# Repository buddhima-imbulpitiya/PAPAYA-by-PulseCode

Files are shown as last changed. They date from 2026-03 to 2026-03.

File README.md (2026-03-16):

## P.A.P.A.Y.A._by_PulseCode

> **Posture Analysis and Proactive Alignment for Your Awareness**  
> A smart cushion that detects poor sitting posture in real-time and provides subtle haptic feedback to encourage healthy sitting habits.

🏆 **2nd Runners Up – Brainstorm 2025**  
📍 **University of Moratuwa – BM1190 Engineering Design Project**

---

## 📜 Project Overview
PulseCode is a human-centered ergonomic solution to combat posture-related back pain among desk-bound individuals.  
It combines **pressure sensors**, **distance sensing**, and **vibration feedback** to help users build healthy sitting habits without intrusive devices.

---

## 🛠 Features
- **8x FSR402 pressure sensors** for seat pressure mapping
- **Ultrasonic sensor (HC-SR04)** for back distance measurement
- **ATmega328P microcontroller** for posture logic
- **Vibration motor** for subtle posture alerts
- **Custom PCB** and **SolidWorks-designed enclosures**
- **LED battery level indicator**, USB-C charging, 7.4V Li-ion battery
- **Automotive-grade foam cushion**

---
**Final Product :**
<p align="center">
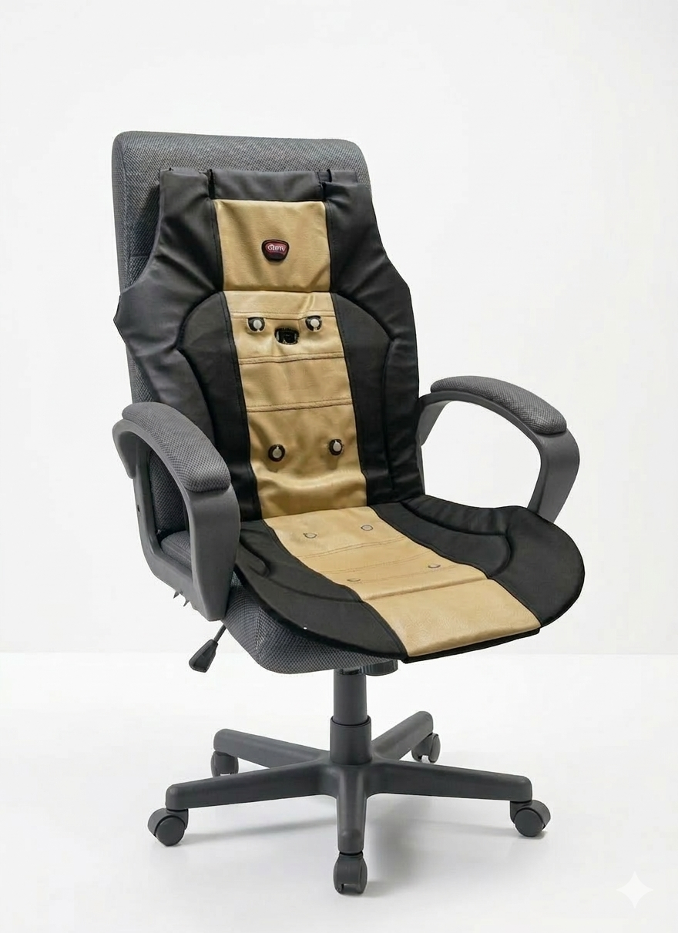
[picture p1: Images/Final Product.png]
  
  &nbsp;&nbsp;&nbsp;&nbsp; &nbsp;&nbsp; &nbsp;  &nbsp; &nbsp; &nbsp;&nbsp; &nbsp; &nbsp; &nbsp; &nbsp; &nbsp; &nbsp; 
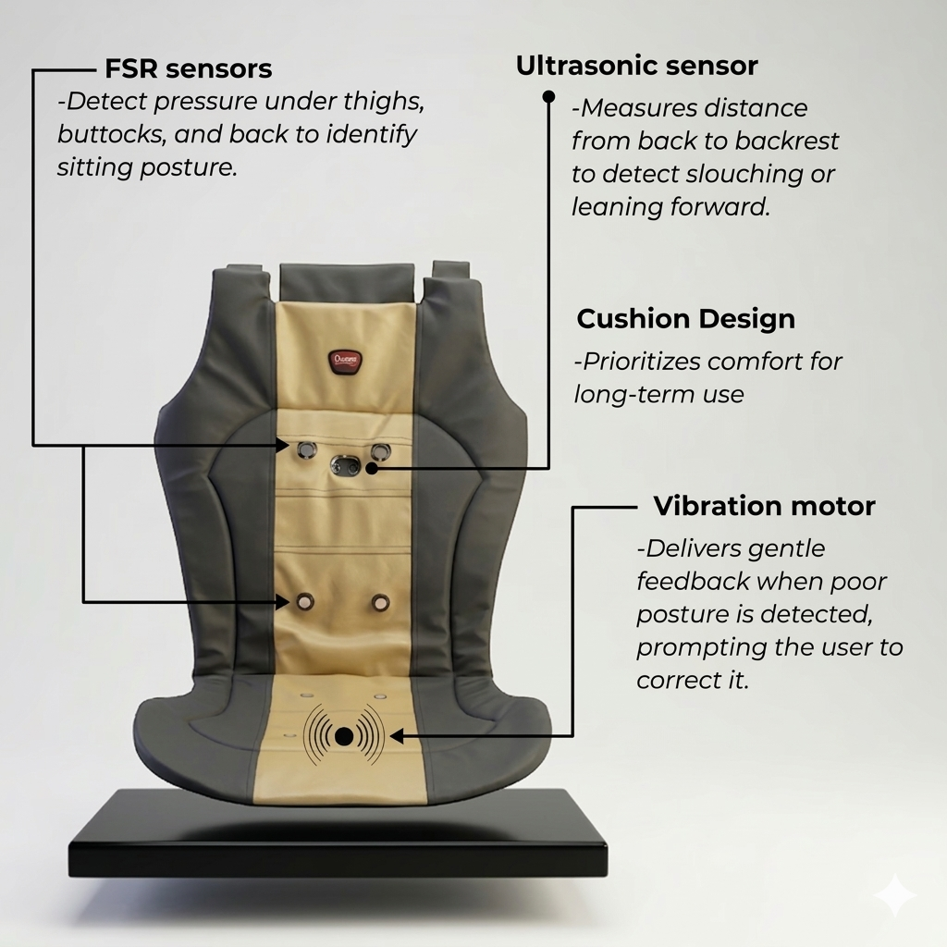
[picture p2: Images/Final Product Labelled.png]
  
  &nbsp;&nbsp;&nbsp;
</p>

---

**System Architecture & Schematic :**

<p align="center">
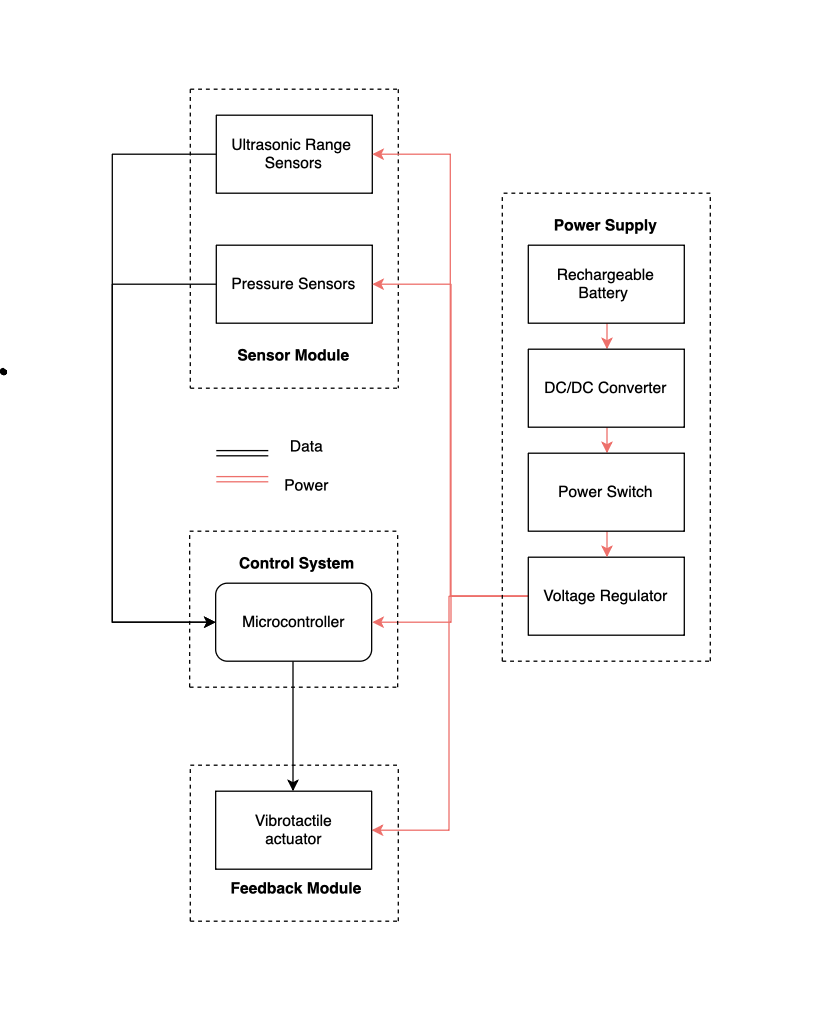
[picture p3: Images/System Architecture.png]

&nbsp;&nbsp;&nbsp;&nbsp; &nbsp;&nbsp; &nbsp;  &nbsp;&nbsp; &nbsp; &nbsp; &nbsp;&nbsp; &nbsp; &nbsp; &nbsp;&nbsp; &nbsp;&nbsp;  &nbsp; &nbsp; &nbsp; &nbsp;&nbsp;  &nbsp;&nbsp;&nbsp; &nbsp;
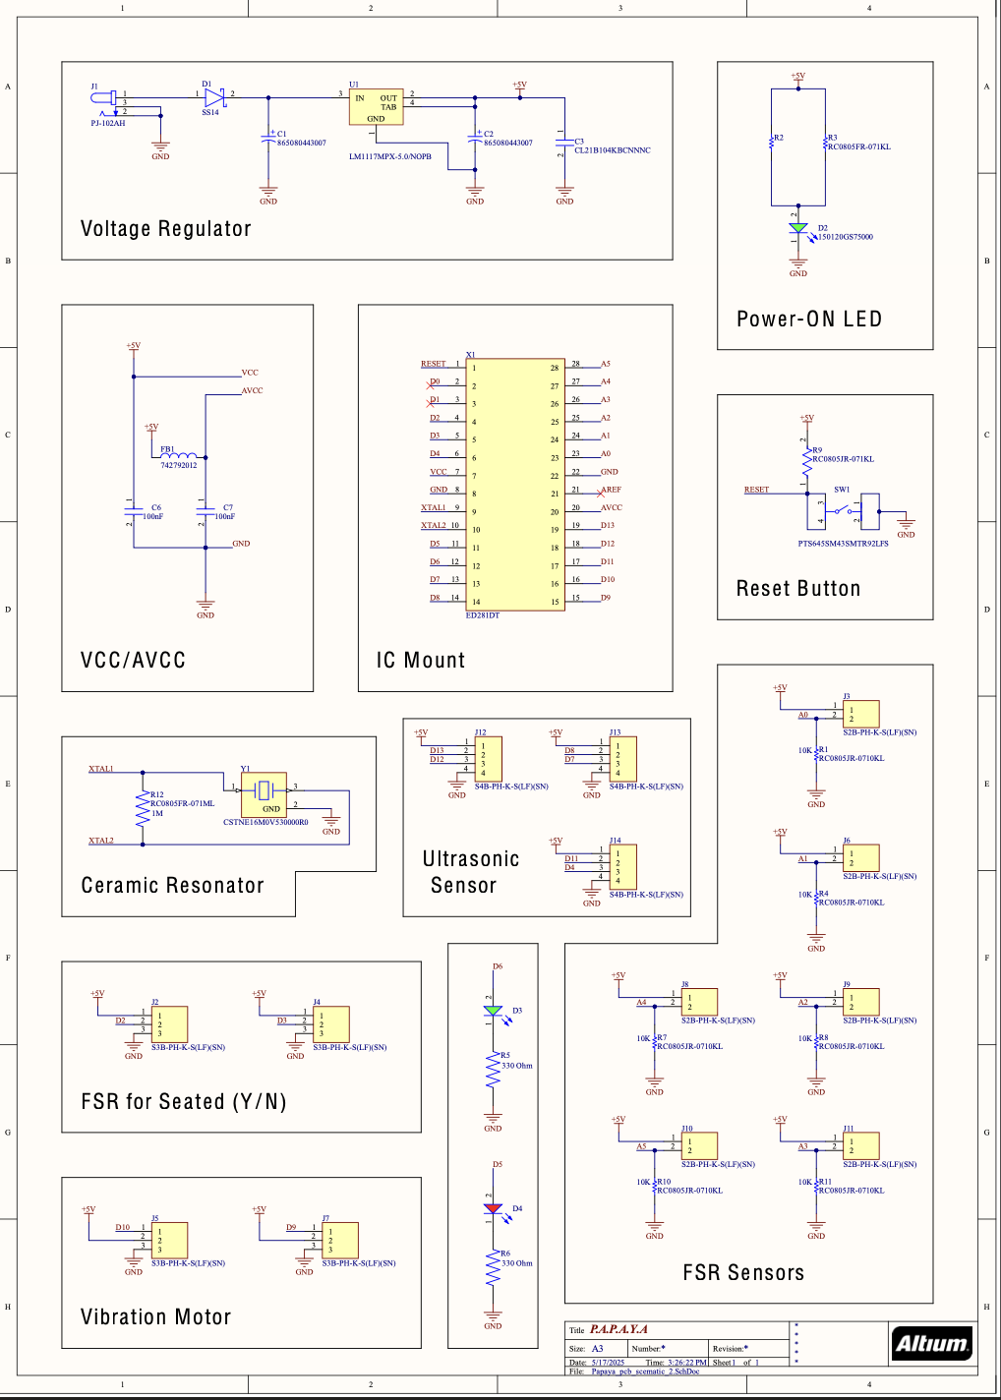
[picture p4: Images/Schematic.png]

</p>

---

**PCB Design :**

<p align="center">
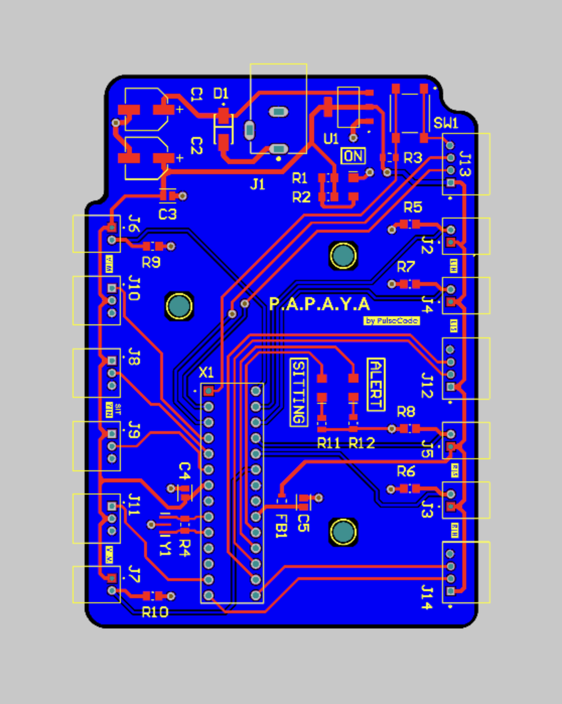
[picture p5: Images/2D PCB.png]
  
  &nbsp;&nbsp;&nbsp;
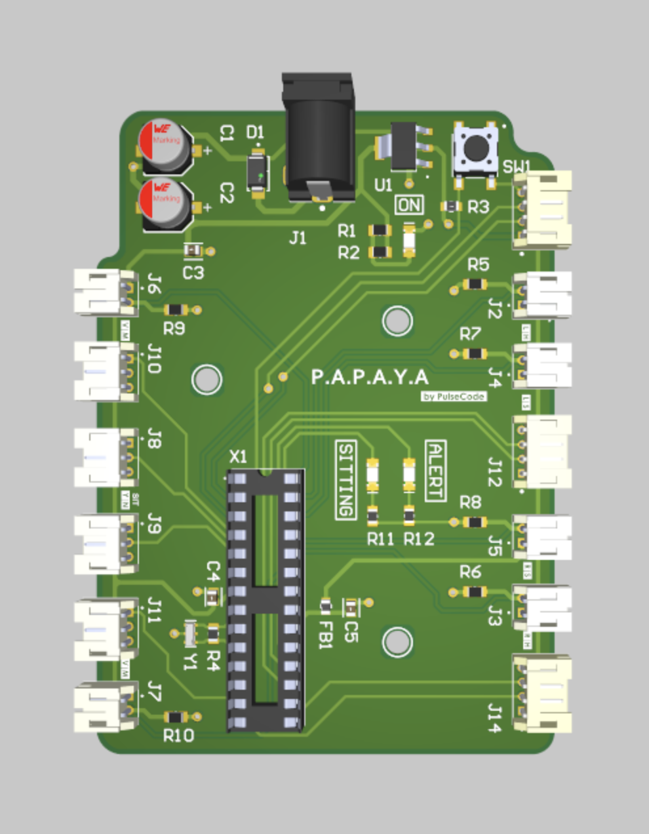
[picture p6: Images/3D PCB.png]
  
  &nbsp;&nbsp;&nbsp;
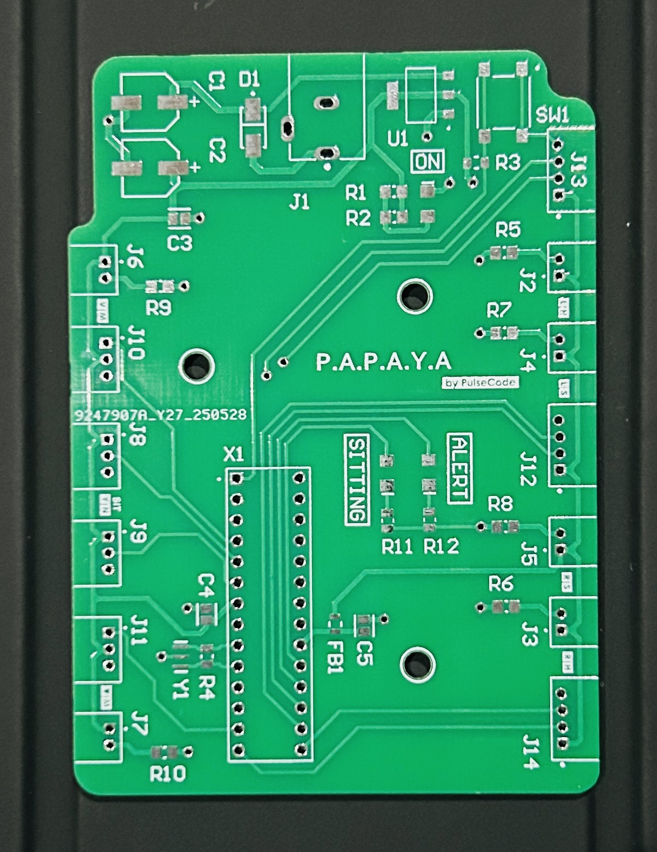
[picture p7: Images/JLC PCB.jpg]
  
</p>

---

**Enclosure Design :**

<p align="center">
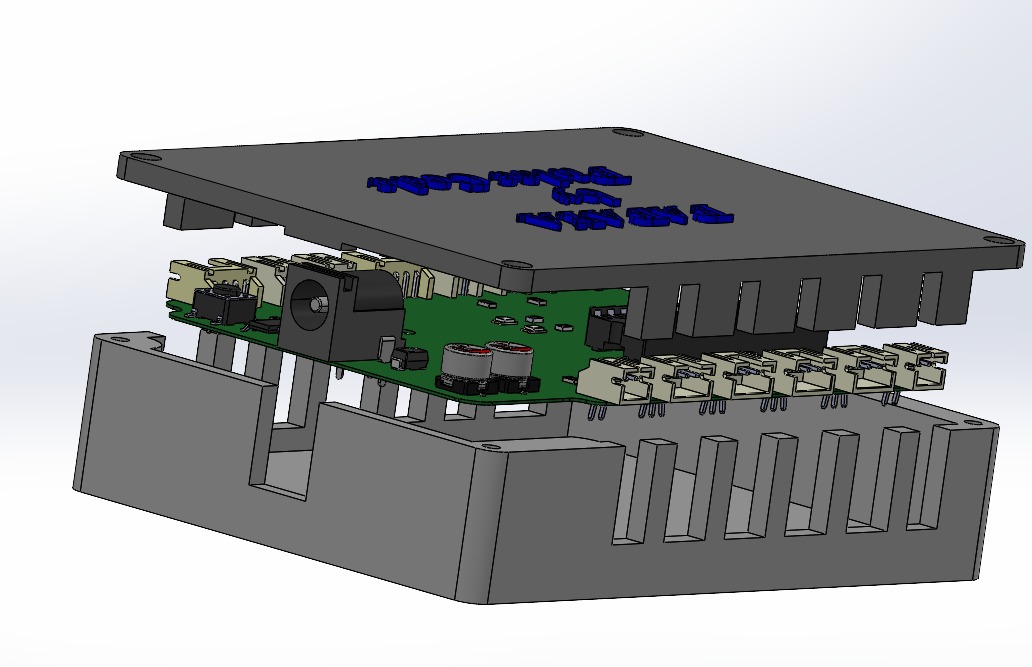
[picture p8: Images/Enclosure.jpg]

  &nbsp;&nbsp;&nbsp;&nbsp;&nbsp;&nbsp;&nbsp;&nbsp;&nbsp;&nbsp;&nbsp;&nbsp;&nbsp;
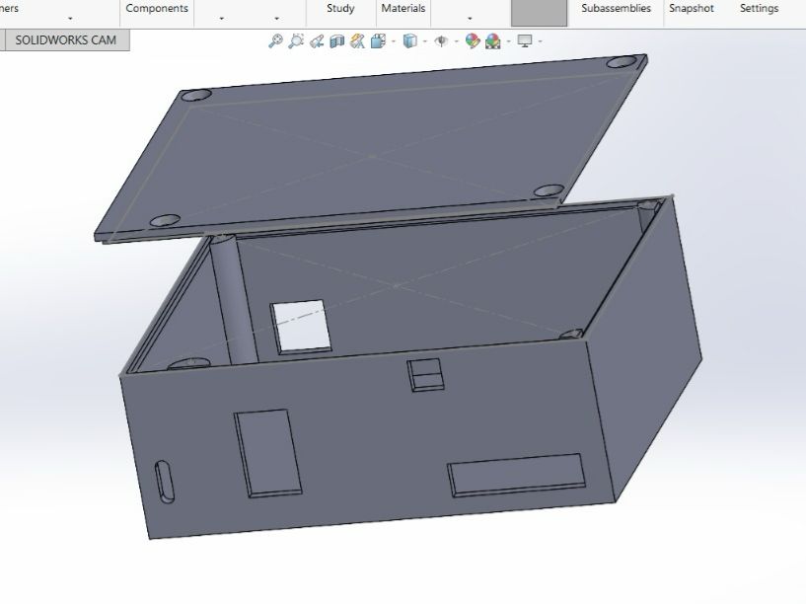
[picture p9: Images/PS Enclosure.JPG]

</p>

---

 ## 📑 Documentation
- [📄 Final Report](Documentation/Prometheus_Final_Report.pdf)  
- [📊 Final Presentation](Documentation/Prometheus_Final_Presentation.pdf)  
- [🎯 Project Pitch Deck](Documentation/Prometheus_Project_Pitch.pdf)  

---

## 👥 Team PulseCode

- [Buddhima Imbulpitiya](https://github.com/buddhima-imbulpitiya)
- [Mokshan Colombage](https://github.com/mokshan-123)
- [Abdul Rahman](https://github.com/Abdul-Rahman-bme)
- [Chaleesha Keerawella](https://github.com/chalee88)

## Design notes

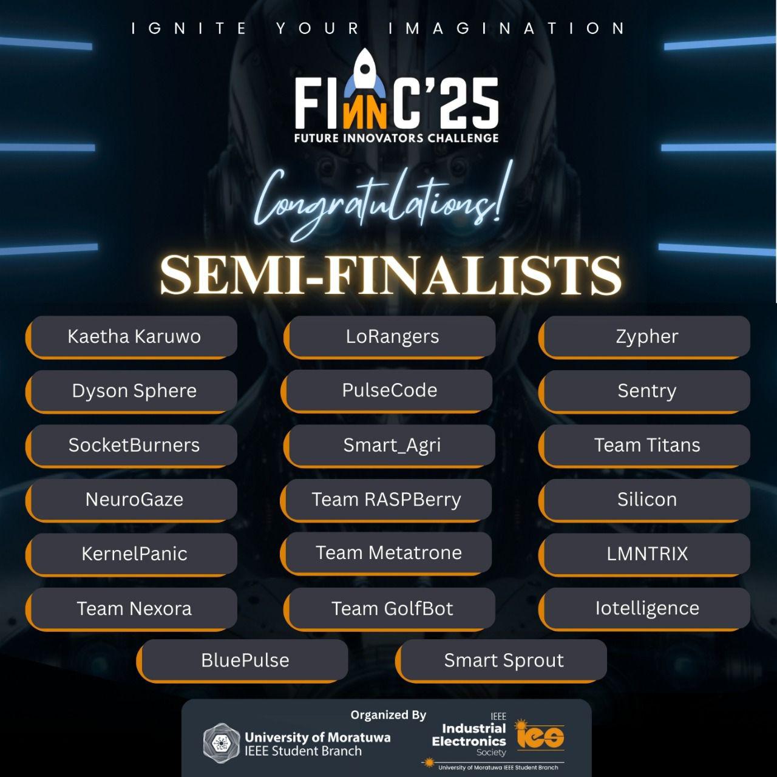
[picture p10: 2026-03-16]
Images/FINNC 25.jpg

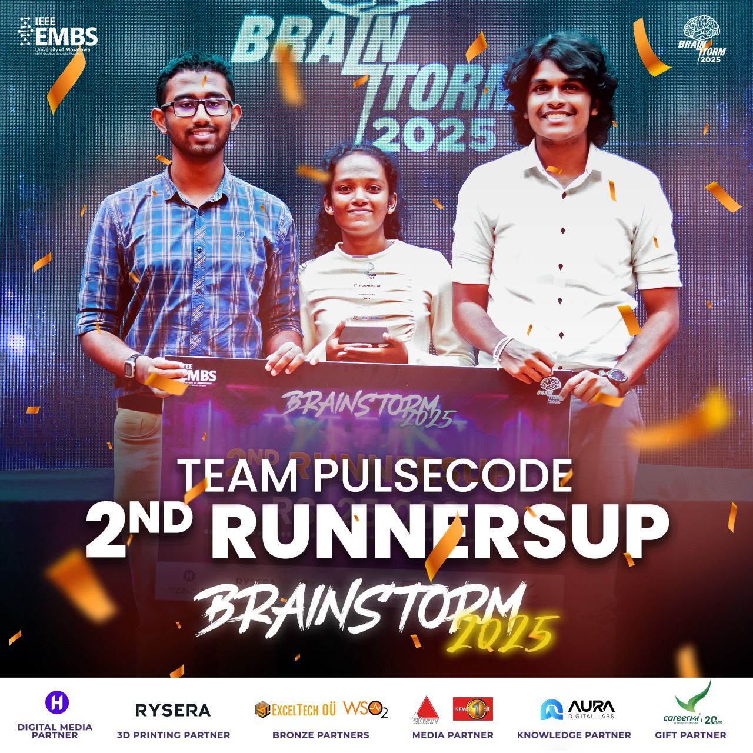
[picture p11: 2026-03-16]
Images/Brainstorm 25.jpg

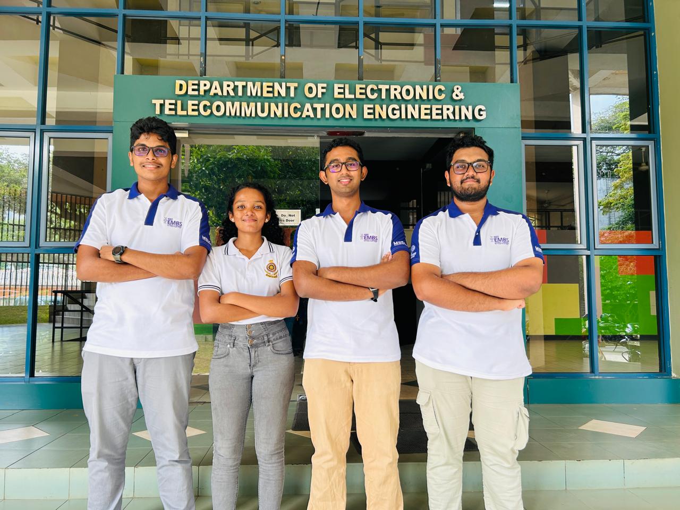
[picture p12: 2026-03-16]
Images/Team PulseCode.jpg

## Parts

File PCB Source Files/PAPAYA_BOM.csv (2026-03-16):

Name | Description | Designator | Part Number | Price | Qty
865080443007 | 865080443007 WCAP-ASLI Aluminum Electrolytic Capacitors | C1, C2 | Wurth Elektronik 865080443007, | 0.54 | 2
CL21B104KBCNNNC | CL21 Series 0805 100nF 50V ±10% Tolerance X7R Multilayer Ceramic Chip Capacitor | C3, C4, C5 | Samsung Electro-Mechanics CL21B104KBCNNNC, | 122 | 3
SS14 | DIODE SCHOTTKY 40V 1A SMA | D1 | onsemi SS14 | 0.29 | 1
150120GS75000 | WURTH ELEKTRONIK - 150080GS75000 - LED, Green, SMD, 0805, 30 mA, 3.2 V, 520 nm | D2, D3 | Wurth Elektronik 150080GS75000, | 0.38 | 2
150120RS75000 | LED Uni-Color Red 630nm 2-Pin Chip 0805(2012Metric) T/R | D4 | Wurth Elektronik 150080RS75000 | 0.19 | 1
BLM21PG300SN1D | Chip Ferrite Bead, 0805, 30Ω @ 100MHz, 0.014Ω, , 4A | FB1 | Murata BLM21PG300SN1D | 0.11 | 1
PJ-102AH | 2.0 x 6.5 mm, 5.0 A, Horizontal, Through Hole, Tapered Pins, Dc Power Jack Connector | J1 |  |  | 1
S2B-PH-K-S(LF)(SN) | Connector Header Through Hole, Right Angle 2 position | J2, J3, J4, J5, J6, J7 |  |  | 6
S3B-PH-K-S(LF)(SN) | Connector Header Through Hole, Right Angle 3 position 0.079" (2.00mm) | J8, J9, J10, J11 |  |  | 4
S4B-PH-K-S(LF)(SN) | Connector Header Through Hole, Right Angle 4 position 0.079 _2.00mm_ | J12, J13, J14 |  |  | 3
RC0805FR-071KL | Chip Resistor, 1 KOhm, +/- 1%, 125 mW, -55 to 155 degC, 0805 (2012 Metric), RoHS, Tape and Reel | R1, R2 | Yageo Group RC0805FR-071KL, | 0.016 | 2
RC0805JR-071KL | RES SMD 1K OHM 5% 1/8W 0805 | R3 | Yageo Group RC0805JR-071KL | 13.5 | 1
RC0805FR-071ML | 1 MOhms Â±1% 0.125W, 1/8W Chip Resistor 0805 (2012 Metric) Moisture Resistant Thick Film | R4 |  |  | 1
RC0805JR-0710KL | Chip Resistor, 10 KOhm, +/- 5%, 0.125 W, -55 to 155 degC, 0805 (2012 Metric), RoHS, Tape and Reel | R5, R6, R7, R8, R9, R10 | Yageo Group RC0805JR-0710KL, | 0.09 | 6
RC0805JR-07330RL | Fixed Resistor, Metal Glaze/thick Film, 0.125W, 330ohm, 150V, 5% +/-Tol, 100ppm/Cel, Surface Mount, 0805 | R11, R12 |  |  | 2
PTS645SM43SMTR92LFS | SWITCH TACTILE SPST-NO 0.05A 12V | SW1 |  |  | 1
AMS1117-5.0_1 | 1A LOW DROPOUT VOLTAGE REGULATOR | U1 |  |  | 1
ED281DT | CONN IC DIP SOCKET 28POS TIN | X1 |  |  | 1
CSTNE16M0V530000R0 | CERAMIC RES 16.0000MHZ 15PF SMD | Y1 | Murata CSTNE16M0V530000R0 | 0.26 | 1

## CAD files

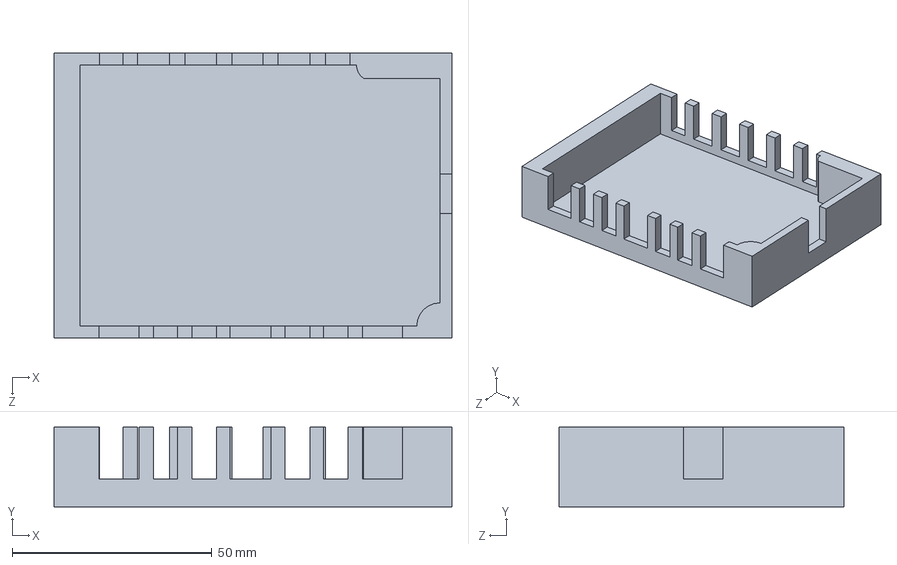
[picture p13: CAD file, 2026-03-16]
Enclosure Source Files/PCB Enclosure/Sub Ass.SLDASM
99.7 x 20.0 x 71.4 mm

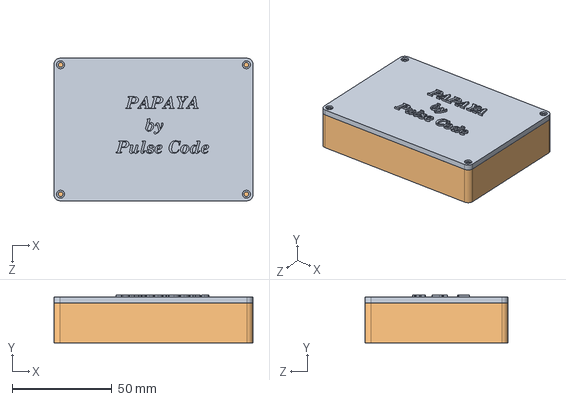
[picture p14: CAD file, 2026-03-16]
Enclosure Source Files/PCB Enclosure/PCB_Full_Assembly.SLDASM
99.7 x 24.0 x 71.4 mm
Fixed Part
lid

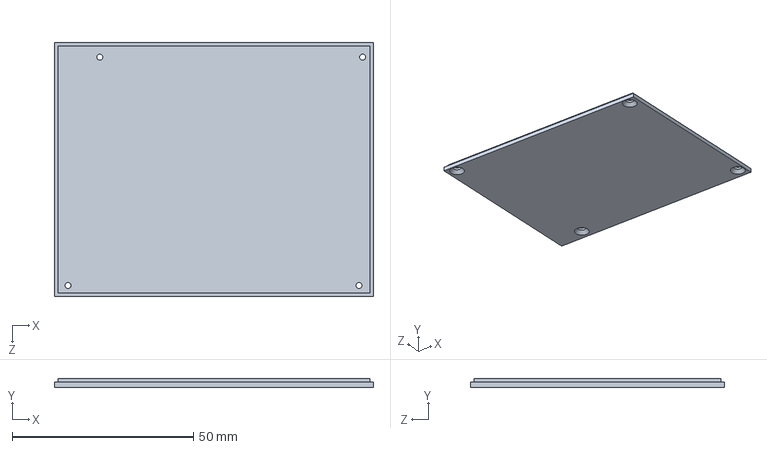
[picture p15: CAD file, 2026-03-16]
Enclosure Source Files/Power Supply enclosure/Battery_Lid_part.SLDPRT
88.0 x 2.50 x 70.0 mm

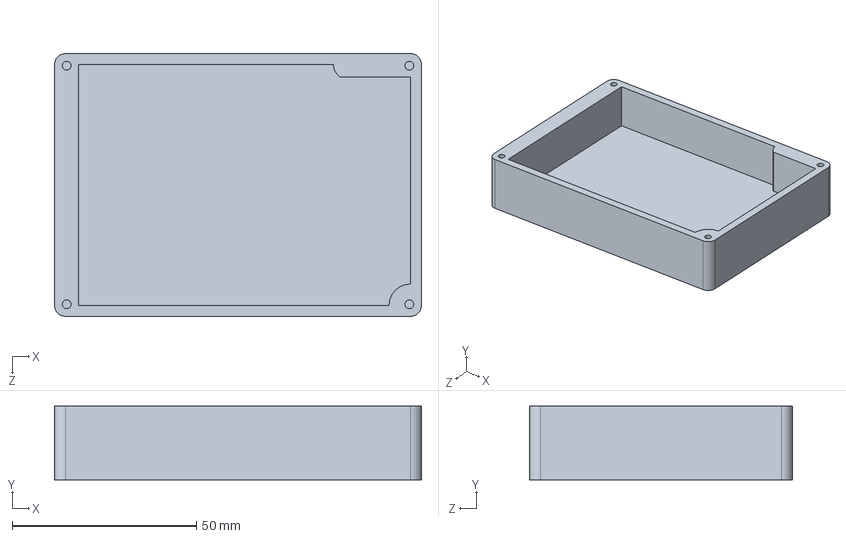
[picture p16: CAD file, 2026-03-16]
Enclosure Source Files/PCB Enclosure/Fixed Part.SLDPRT
99.7 x 20.0 x 71.4 mm

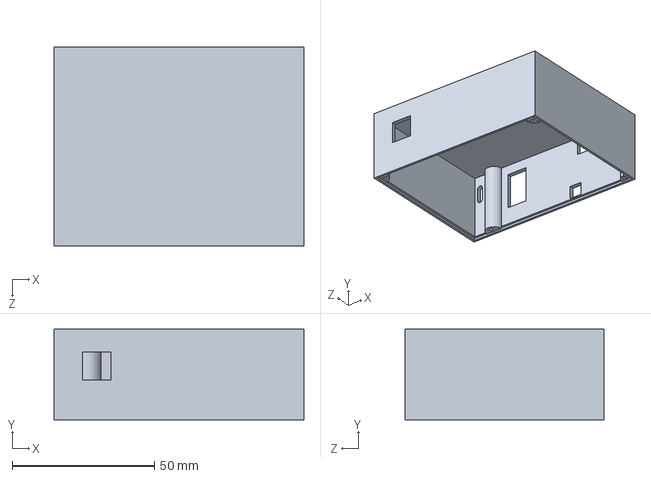
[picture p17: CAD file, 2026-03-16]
Enclosure Source Files/Power Supply enclosure/Battery_Fixed_part.SLDPRT
88.0 x 32.0 x 70.0 mm

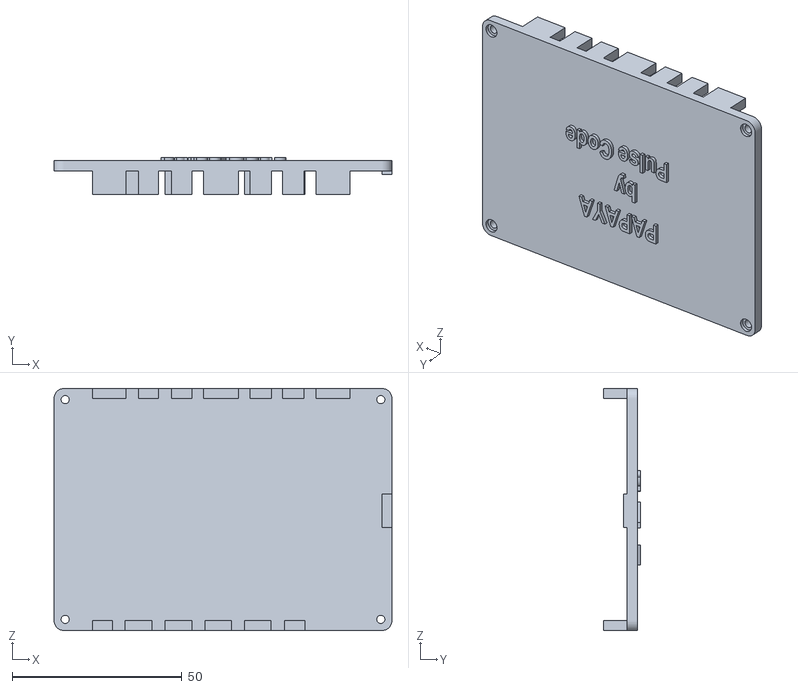
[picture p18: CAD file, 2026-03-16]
Enclosure Source Files/PCB Enclosure/PAPAYAEnclosure_modified - lid-1.STL
99.6 x 11.0 x 71.4

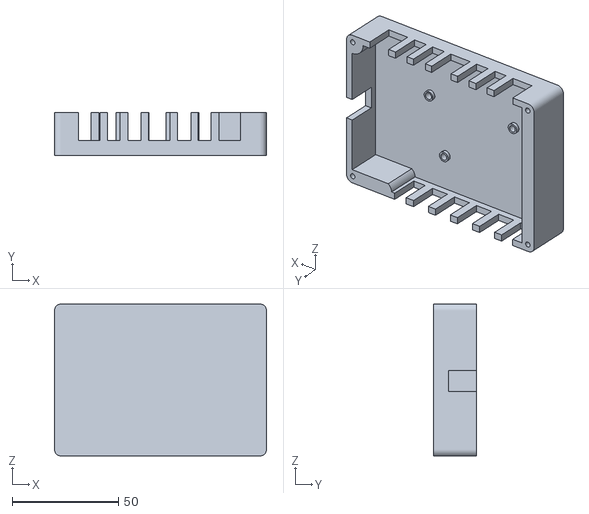
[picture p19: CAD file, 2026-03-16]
Enclosure Source Files/PCB Enclosure/PAPAYAEnclosure_modified - Sub Ass-1 Fixed Part-1.STL
99.6 x 20.0 x 71.4

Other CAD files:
Enclosure Source Files/PCB Enclosure/lid.SLDPRT

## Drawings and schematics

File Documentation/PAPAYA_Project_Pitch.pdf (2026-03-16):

### TEAM PROMETHEUS

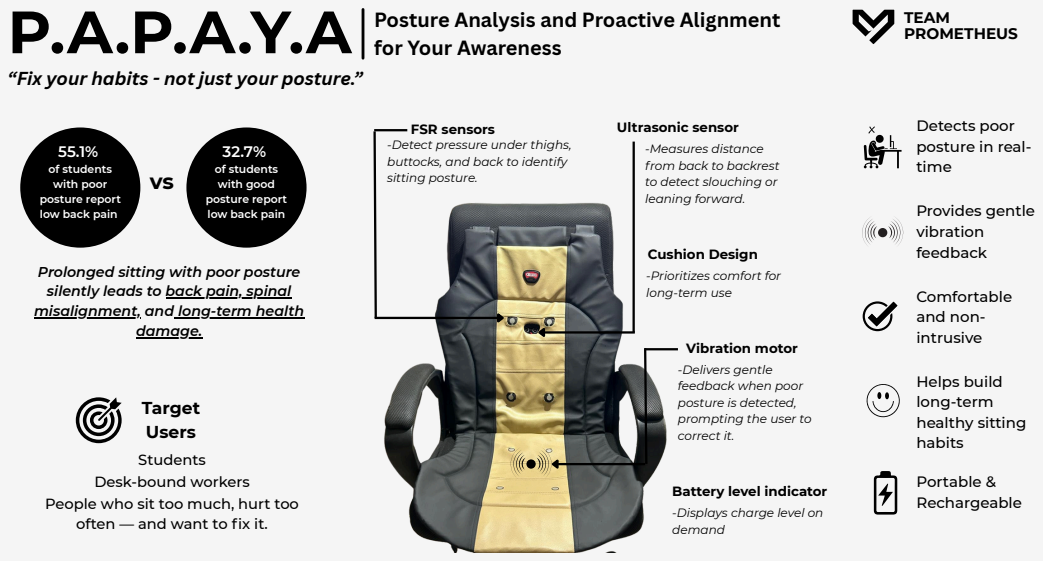
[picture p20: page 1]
of students; damage.; FSR sensors; Ultrasonic sensor; Desk-bound workers; Battery level indicator; Provides gentle vibration feedback; Comfortable and non- intrusive; Helps build long-term healthy sitting habits; Portable & Rechargeable

Posture Analysis and Proactive Alignment
for Your Awareness

“Fix your habits - not just your posture.”

-Detect pressure under thighs,
buttocks, and back to identify
sitting posture.

Detects poor
posture in real-
time

of students
with poor
posture report
low back pain

-Measures distance
from back to backrest
to detect slouching or
leaning forward.

with good

Cushion Design
-Prioritizes comfort for
long-term use

Prolonged sitting with poor posture
silently leads to back pain, spinal
misalignment, and long-term health

Vibration motor
-Delivers gentle
feedback when poor
posture is detected,
prompting the user to
correct it.

Target
Users
Students
People who sit too much, hurt too
often — and want to fix it.

-Displays charge level on
demand

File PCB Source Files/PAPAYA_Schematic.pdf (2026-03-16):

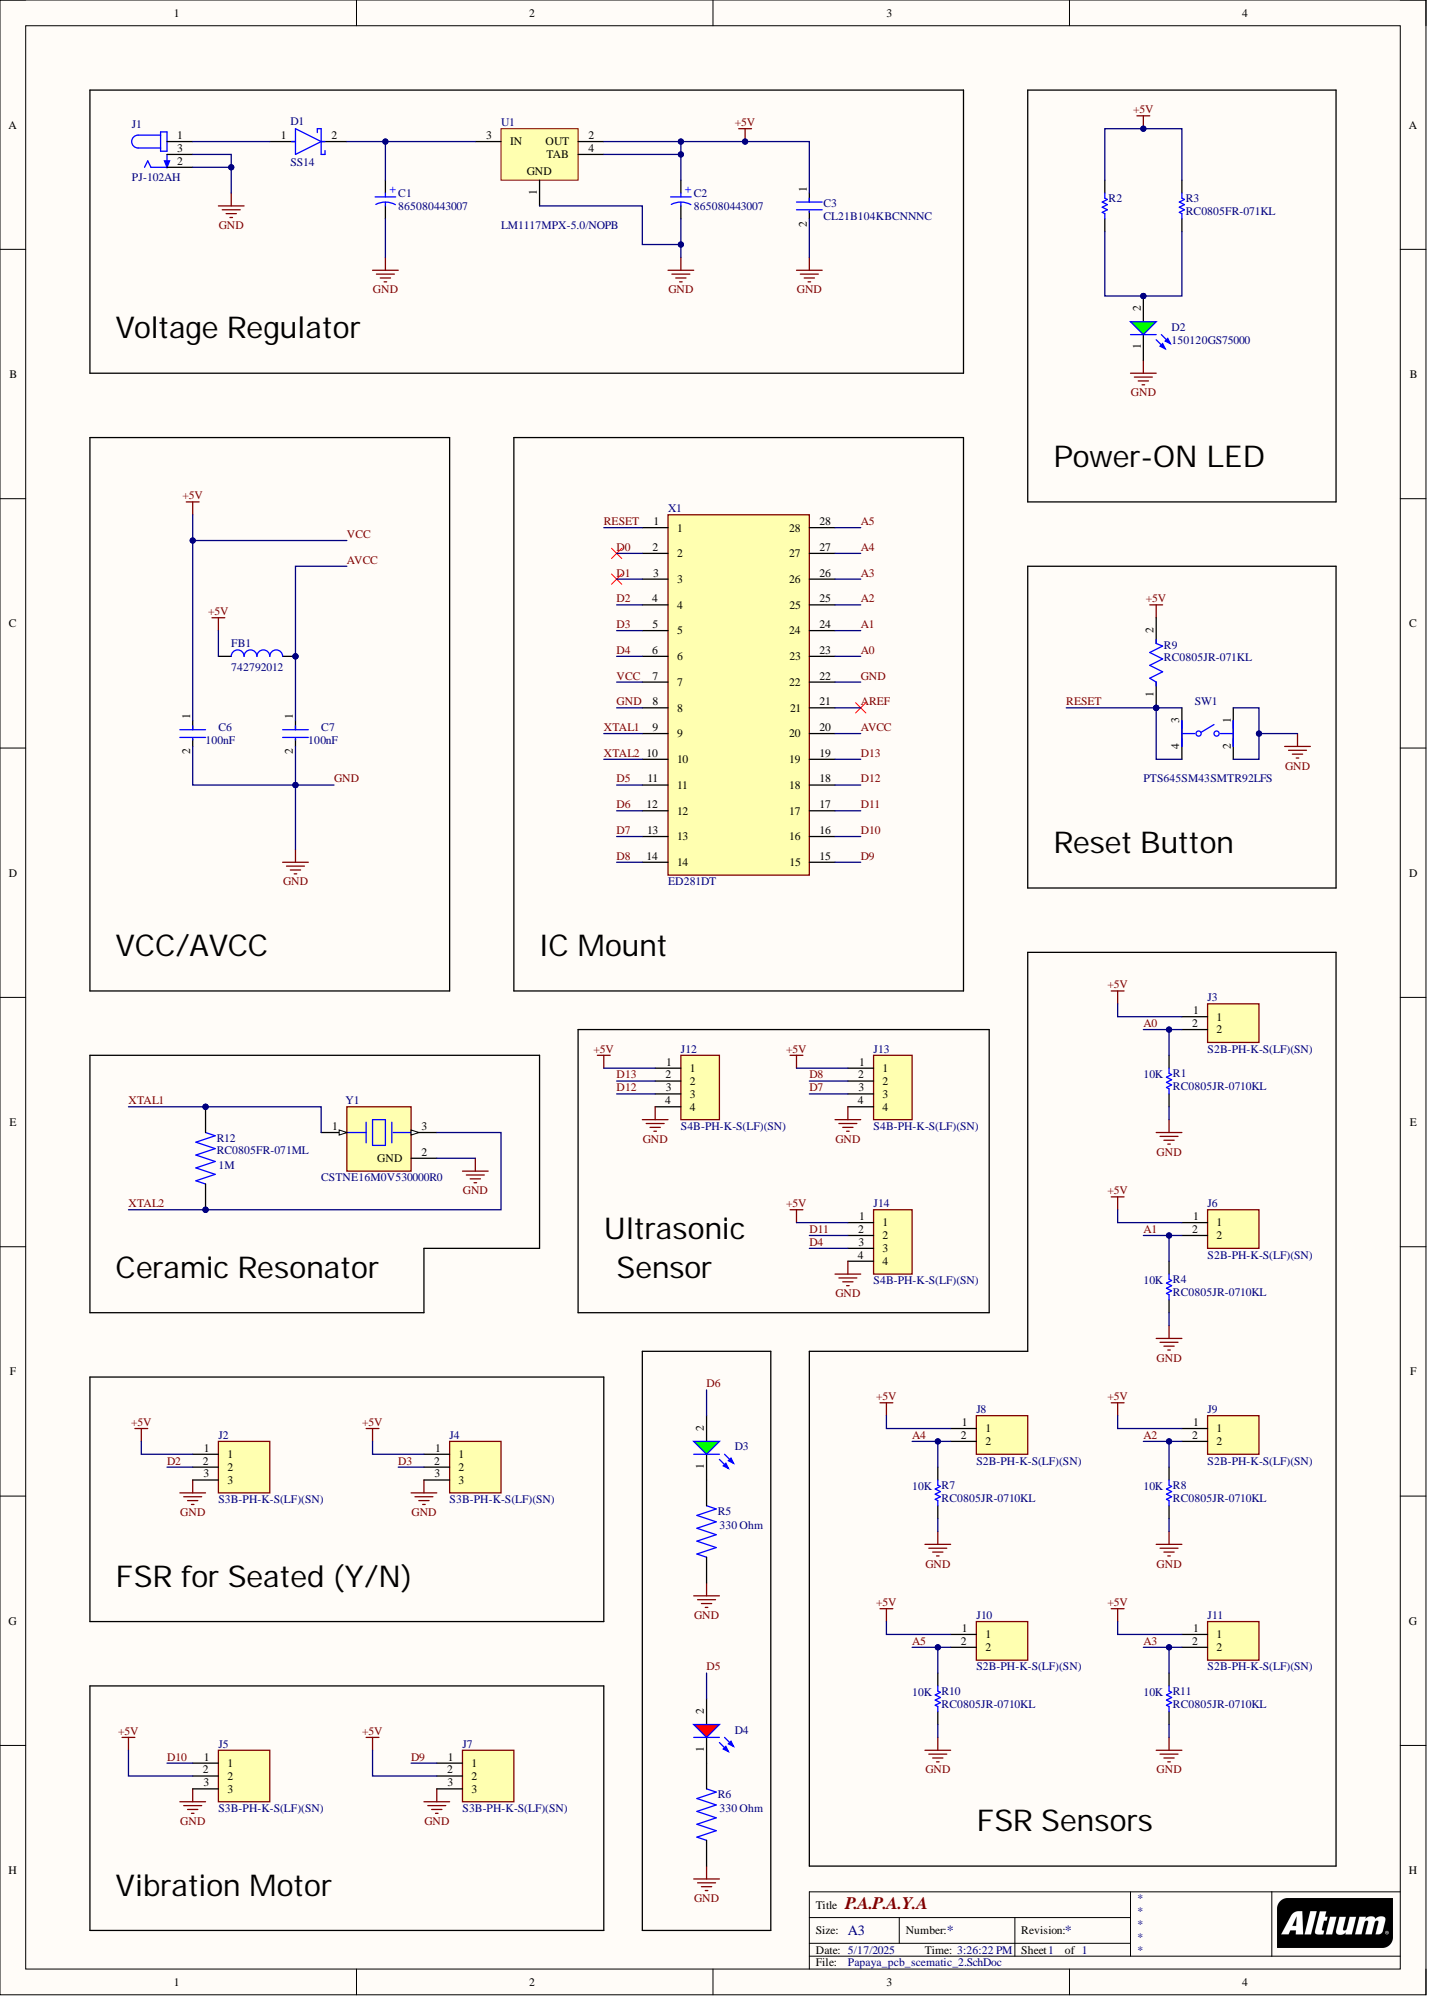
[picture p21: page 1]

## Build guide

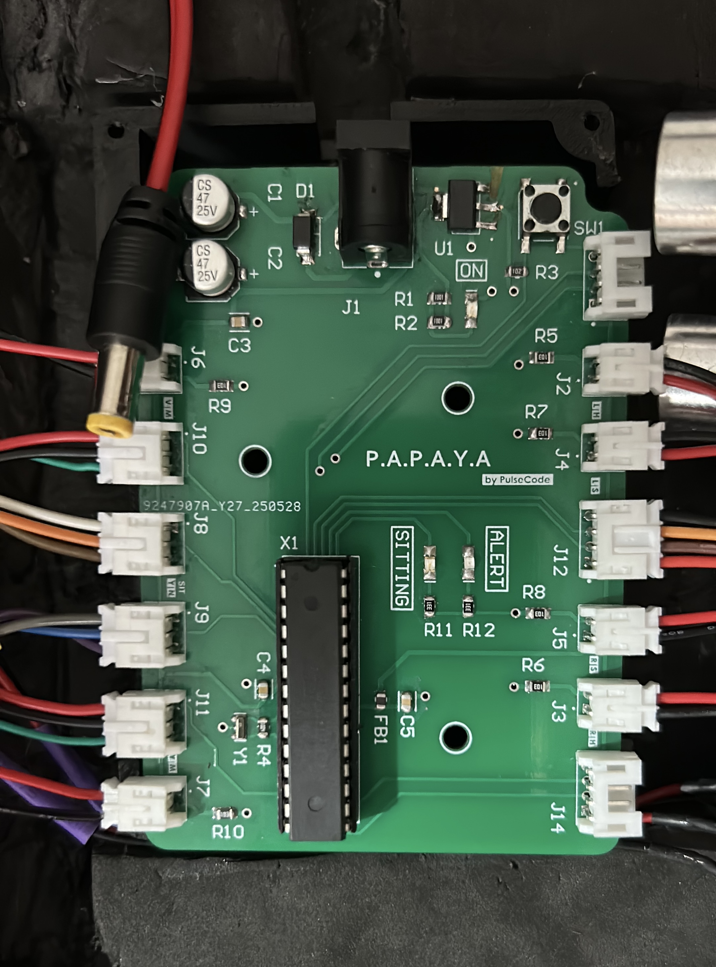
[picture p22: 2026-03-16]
Images/Assembled PCB.jpg

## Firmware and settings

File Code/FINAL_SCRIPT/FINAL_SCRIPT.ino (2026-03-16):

// C++ code

//backrest
const int fsrPin1 = A2;
const int fsrPin2 = A3;
const int fsrPin3 = A0;
const int fsrPin4 = A1;
const int fsrPin5 = A4;
const int fsrPin6 = A5;

//sitting
const int fsrPin7 = 3;
const int fsrPin8 = 4;

const int ledPin2 = 12;
const int ledPin1 = 13;

const int trigPin1 = 10;
const int echoPin1 = 11;

// Motor
const int motorPin1 = 7;
const int motorPin2 = 2;
unsigned long badPostureStartTime = 0;
bool isBadPosture = false;

const unsigned long delayDuration = 1000;  // 1 second in milliseconds

long duration1;
float distance1;

const int fsrThreshold = 100;  // Adjust this based on testing
const float distanceThreshold = 10.0; // in cm

void setup() {
  Serial.begin(9600);

  pinMode(fsrPin1, INPUT);
  pinMode(fsrPin2, INPUT);
  pinMode(fsrPin3, INPUT);
  pinMode(fsrPin4, INPUT);
  pinMode(fsrPin5, INPUT);
  pinMode(fsrPin6, INPUT);
  
  pinMode(fsrPin7, INPUT);
  pinMode(fsrPin8, INPUT);

  pinMode(ledPin1, OUTPUT);
  pinMode(ledPin2, OUTPUT);

  pinMode(trigPin1, OUTPUT);
  pinMode(echoPin1, INPUT);

  pinMode(motorPin1, OUTPUT);
  digitalWrite(motorPin1, LOW);

  pinMode(motorPin2, OUTPUT);
  digitalWrite(motorPin2, LOW);
 
}

void loop() {
  int fsrState1 = digitalRead(fsrPin7);
  int fsrState2 = digitalRead(fsrPin8);
  
  digitalWrite(trigPin1, LOW);
  delayMicroseconds(2);
  digitalWrite(trigPin1, HIGH);
  delayMicroseconds(10);
  digitalWrite(trigPin1, LOW);
  duration1 = pulseIn(echoPin1, HIGH);
  distance1 = duration1 * 0.034 / 2;  

  if (fsrState1 == LOW && fsrState2 == LOW) {  // Sitting
    digitalWrite(ledPin1, HIGH);

    int fsrState3 = analogRead(fsrPin1);
    int fsrState4 = analogRead(fsrPin2);
    int fsrState5 = analogRead(fsrPin3);
    int fsrState6 = analogRead(fsrPin4);
    int fsrState7 = analogRead(fsrPin5);
    int fsrState8 = analogRead(fsrPin6);

    if (fsrState3 > fsrThreshold && fsrState4 > fsrThreshold && fsrState5 > fsrThreshold && fsrState6 > fsrThreshold && fsrState7 > fsrThreshold && fsrState8 > fsrThreshold) {
      digitalWrite(ledPin2, LOW);
      digitalWrite(motorPin1, LOW);
      digitalWrite(motorPin2, LOW);
      badPostureStartTime = 0;
      isBadPosture = false;
    } 
    else if (fsrState3 < fsrThreshold && fsrState4 < fsrThreshold && fsrState5 > fsrThreshold && fsrState6 > fsrThreshold && fsrState7 > fsrThreshold && fsrState8 > fsrThreshold && distance1 < distanceThreshold) {
      digitalWrite(ledPin2, LOW);
      digitalWrite(motorPin1, LOW);
      digitalWrite(motorPin2, LOW);
      badPostureStartTime = 0;
      isBadPosture = false;
    } 
    else {
      digitalWrite(ledPin2, HIGH);

      if (!isBadPosture) {
        badPostureStartTime = millis();
        isBadPosture = true;
      } else {
        if (millis() - badPostureStartTime >= delayDuration) {
          if ((millis() / 1000) % 2 == 0) {
            digitalWrite(motorPin1, HIGH);
            digitalWrite(motorPin2, HIGH);
          } else {
            digitalWrite(motorPin1, LOW);
            digitalWrite(motorPin2, LOW);
          }
        }
      }
    }
  } 
  else {
    digitalWrite(ledPin1, LOW);
    digitalWrite(ledPin2, LOW);
    digitalWrite(motorPin1, LOW);
    digitalWrite(motorPin2, LOW);
    badPostureStartTime = 0;
    isBadPosture = false;
  }

  delay(100);  // Give sensors time to settle
}

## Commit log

2026-03-16 Uploaded PCB Files
    [PAPAYA_BOM.csv, PAPAYA_PCB.PcbDoc, PAPAYA_PCB.SchDoc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]
2026-03-16 Uploaded Enclosure Source Files
    [Battery_Fixed_part.SLDPRT, Battery_Lid_part.SLDPRT, Fixed Part.SLDPRT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]
2026-03-16 Create PS Enclosure.JPG
